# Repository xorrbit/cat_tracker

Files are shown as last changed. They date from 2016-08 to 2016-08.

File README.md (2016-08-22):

# Cat Tracker

This Ardunio project reads location data from a GPS module and writes waypoints to a GPX file on a MicroSD card.

# A Bit More Technical info

This parses NMEA messages sent over a serial channel at 9600 bps. I've configured the NEO-7M to send out updates in low power mode at a rate of 1 Hz. It looks for GPRMC messages to get the lat/lon and date/time, and GPGSA messages to get the PDOP (position degree of precision) / HDOP (horizontal degree of precision) / VDOP (vertical degree of precision).

Once it has this info it creates a new file on the SD card, with the filename based on the date/time as DDHHMMSS.GPX, and starts writing GPX trkpt elements.

It was initially developed for the MSP430 microcontroller but the limited SRAM caused me to port it over to Arduino.

# Development
Since my GPS module/antenna (a uBlox NEO-7M) gets horrible reception indoors, I had to do most of my development and testing outside, so I set up a workstation on my balcony.



This was prototype #2 - switched to an Ardweeny on a breadboard instead of using a full Arduino.


This was prototype #3 - 3xAAA batteries for power, the Ardweeny and MicroSD card adapter (all soldered up), and the GPS module.


Prototype #3 but all taped up in a compact-ish package. SNES cart for scale. Weighs in at 85g or so, with 35g of that being the batteries.




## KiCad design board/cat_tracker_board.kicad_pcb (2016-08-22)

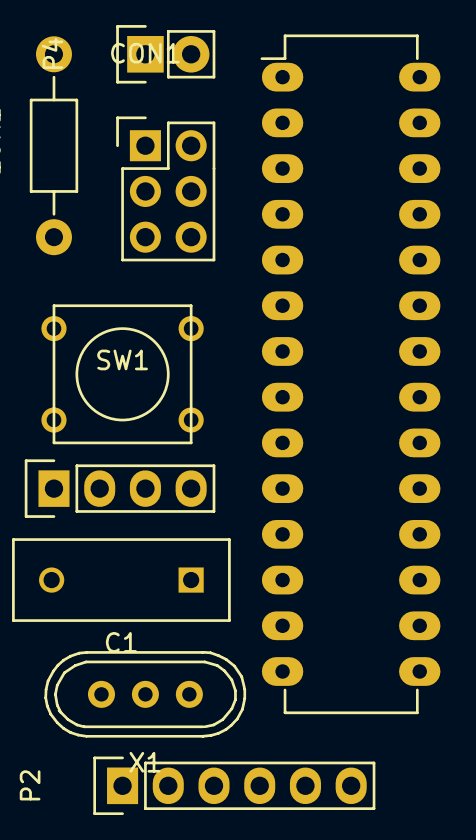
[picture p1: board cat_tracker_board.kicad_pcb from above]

Board: 2 copper layers, 9 parts (0 on the bottom side), 10 nets, no tracks yet.

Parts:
10K1: R; Resistor_Horizontal_RM10mm
C1: 0.1u; C_Disc_D12_P7.75
CON1: AVR-ISP-6; Pin_Header_Straight_2x03
IC1: ATMEGA328-P; DIP-28_W7.62mm_LongPads
P1: GPS_NMEA; Pin_Header_Straight_1x04
P2: MicroSD Card Adapter; Pin_Header_Straight_1x06
P4: BATTERY; Pin_Header_Straight_1x02
SW1: RESET; SW_PUSH_SMALL
X1: 16Mhz XTAL; Crystal_HC49-U_Vertical_3Pin

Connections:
+BATT: 10K1.1, C1.1, CON1.2, IC1.7, IC1.20, IC1.21, P1.1, P2.5, P4.1
GND: C1.2, CON1.6, IC1.8, IC1.22, P1.4, P2.6, P4.2, SW1.2, X1.3
unnamed: 10K1.2, CON1.5, IC1.1, SW1.1
unnamed: CON1.1, IC1.18, P2.4
unnamed: CON1.3, CON1.4, IC1.19, P2.2
unnamed: IC1.9, X1.2
unnamed: IC1.10, X1.1
unnamed: IC1.15, P1.2
unnamed: IC1.16, P2.1
unnamed: IC1.17, P2.3

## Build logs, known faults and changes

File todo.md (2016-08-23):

# To Do
* Get atmega running at lower frequency to save power. Currently it runs at 16 MHz, and a quick test changing the clock prescaler shows it doesn't work properly at 1 MHz, this may be because either the SoftSerial library or the SD card library depends on the 16 MHz clock for some dumb reason.

* Use some low power modes on the atmega. Can turn off the ADC, whatever timers aren't being used, etc. Also can sleep the CPU in between GPS updates, and have it wake up when there is UART activity from the GPS.

* Possibly only turn on the GPS module intermittently. Once every minute or 30 seconds would save a lot of power. It only takes 3 seconds to get a fix upon "hot" power up, which is if all the old satellites it had when powered down are still in view.

* Add a lipo low-voltage cutoff circuit to the schematic, such that you can hook a 1S lipo up to it and run it until it's "dead" (use 80% of the charge) without ruining the lipo. Here is an example, using a S-8261 battery protection IC: https://github.com/rororor/li_prot-02

* Change the footprints to all SMD stuff and make the battery connector footprint a JST plug suitable for a 1S lipo.

* Add open source hardware logo to pcb.

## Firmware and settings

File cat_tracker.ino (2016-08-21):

// xorrbit/cat_tracker

// on prototype
// new gps wiring is
// yellow = gnd
// white = tx
// red = rx (unused)
// black = vcc (lol)

// GPS TX connects to SoftSerial RX (D9, PB9, atmega328 pin 15)
// SoftSerial TX should be set to an unused pin
#define SOFTSERIAL_RX 9
#define SOFTSERIAL_TX 8

// * SD card attached to SPI bus as follows:
// ** CS   - D10 (PB2, atmega328 pin 16)
// ** MOSI - D11 (PB3, atmega328 pin 17)
// ** MISO - D12 (PB4, atmega328 pin 18)
// ** CLK  - D13 (PB5, atmega328 pin 19)
#define SD_CHIP_SELECT 10

#include <SPI.h>
#include <SD.h>
#include <SoftwareSerial.h>
#include <stdlib.h>

#define MAX_NMEA 128
#define MAX_DATETIME 23
#define MAX_FILENAME 11

bool STILL_STARTING = true;
char nmea[MAX_NMEA+1];
double lat = 0.0;
double lon = 0.0;
char datetime[MAX_DATETIME+1];
int i;
unsigned char checksum;
char str[MAX_DATETIME];
File dataFile;
bool sd_working = false;
char filename[MAX_FILENAME+1]; // 08202327.GPX aka MMDDHHMMSS.GPX
double hdop = 99.9;
double pdop = 99.9;
double vdop = 99.9;

SoftwareSerial mySerial(SOFTSERIAL_RX, SOFTSERIAL_TX); // RX, TX

#define logPrint(__blah__) Serial.print(__blah__); if (sd_working) dataFile.print(__blah__)
#define logPrintln(__blah__) Serial.println(__blah__); if (sd_working) dataFile.println(__blah__)

void setup()
{
  Serial.begin(9600);
  while (!Serial)
  {
    ; // wait for serial port to connect. Needed for native USB port only
  }

  // see if the card is present and can be initialized:
  if (!SD.begin(SD_CHIP_SELECT)) {
    Serial.println("Card failed, or not present, only logging to serial port!");
  }

  // we wait for the first good GPS message to get the date and time for this header.
  // we also use this for the log file name

  mySerial.begin(9600);
}

void loop()
{
  if (mySerial.available())
  {
    nmea[0] = mySerial.read();
    
    // if we hit a $, read until a newline
    if (nmea[0] == '$')
    {
      i = 1;
      do
      {
        while (mySerial.available() < 1); // wait for next char
        nmea[i] = mySerial.read();
      } while (nmea[i++] != '\n' && (i < MAX_NMEA));
      
      nmea[--i] = '\0';

      // nmea now contains the message (or the most we could grab of it)
      checkNMEA(nmea);
    }
  }
}

void checkNMEA(char *nmea)
{
  if (nmea[1] == 'G' &&
      nmea[2] == 'P' &&
      nmea[3] == 'R' &&
      nmea[4] == 'M' &&
      nmea[5] == 'C')
  {
    // double check our checksum
    if (calcChecksum(nmea) == (unsigned char) strtoul(&nmea[i-3], 0, 16))
    {
      // this parses out data if we have a fix
      if (parseGPRMC(nmea, &lat, &lon, datetime))
      {
        logGPS(&lat, &lon, datetime, &pdop, &hdop, &vdop); 
      }
    }
  }
  else if (nmea[1] == 'G' &&
           nmea[2] == 'P' &&
           nmea[3] == 'G' &&
           nmea[4] == 'S' &&
           nmea[5] == 'A')
  {
    // double check checksum
    if (calcChecksum(nmea) == (unsigned char) strtoul(&nmea[i-3], 0, 16))
    {
      // parse out pdop, hdop, and vdop
      parseGPGSA(nmea, &pdop, &hdop, &vdop);
    }
  }
}

void logGPS(double *lat, double *lon, char *datetime, double *pdop, double *hdop, double *vdop)
{
  // if our degree of precision is redic high just skip logging
  if (*pdop > 10.0)
    return;

  if (STILL_STARTING)
  {
    // this fixes a weird bug
    // if we don't read sd_working at least once here, the datetime doesn't get output the first time
    if (sd_working) delay(1);
    // DDHHMMSS.GPX aka
    // 2016-08-20T23:27:14.00Z -> 20232714.gpx
    filename[0] = datetime[8];
    filename[1] = datetime[9];
    filename[2] = datetime[11];
    filename[3] = datetime[12];
    filename[4] = datetime[14];
    filename[5] = datetime[15];
    filename[6] = datetime[17];
    filename[7] = datetime[18];
    filename[8] = '.';
    filename[9] = 'G';
    filename[10] = 'P';
    filename[11] = 'X';
    filename[12] = '\0';
    
    dataFile = SD.open(filename, FILE_WRITE);
    if (dataFile)
    {
      sd_working = true;
    }

    logPrintln("<?xml version=\"1.0\" encoding=\"UTF-8\" standalone=\"no\" ?>");
    logPrintln("<gpx creator=\"cat_tracker by xorrbit\">");
    logPrint("<metadata><link href=\"https://github.com/xorrbit/cat_tracker\"><text>xorrbit/cat_tracker on GitHub</text></link><time>");
    logPrint(datetime);
    logPrintln("</time></metadata>");
    logPrintln("<trk><trkseg>");
        
    STILL_STARTING = false;
  }
  else
  {
    // overwrite the footer :)
    if (sd_working)
    {
      dataFile.seek(dataFile.position() - 23);
    }
  }
  
  logPrint("<trkpt lat=\"");
  dtostrf(*lat, 4, 6, str);
  logPrint(str);
  logPrint("\" lon=\"");
  dtostrf(*lon, 4, 6, str);
  logPrint(str);
  logPrint("\"><time>");
  logPrint(datetime);
  logPrint("</time><pdop>");
  dtostrf(*pdop, 4, 2, str);
  logPrint(str);
  logPrint("</pdop><hdop>");
  dtostrf(*hdop, 4, 2, str);
  logPrint(str);
  logPrint("</hdop><vdop>");
  dtostrf(*vdop, 4, 2, str);
  logPrint(str);
  logPrintln("</vdop></trkpt>");
  
  logPrintln("</trkseg></trk></gpx>");

  if (sd_working)
  {
    dataFile.flush();
  }
}

// parse out PDOP (position dilution of precision), HDOP (horizontal dilution of precision), and VDOP (vertical dilution of precision)
void parseGPGSA(char *nmea, double *pdop, double *hdop, double *vdop)
{
  int i = 0;
  int j = 0;
  char dop[10];
  
  // $GPGSA,A,3,,,,,,16,18,,22,24,,,3.6,2.1,2.2*3C
  for (j = 0; j < 15; j++)
  {
    while(nmea[i++] != ','); // skip first 15 fields
  }

  j = 0;
  while(nmea[i] != ',' && nmea[i] != '*')
  {
    dop[j++] = nmea[i++];
  }
  dop[j] == '\0';

  *pdop = strtod(dop, 0);

  i++;
  j = 0;
  while(nmea[i] != ',' && nmea[i] != '*')
  {
    dop[j++] = nmea[i++];
  }
  dop[j] == '\0';

  *hdop = strtod(dop, 0); 

  i++;
  j = 0;
  while(nmea[i] != ',' && nmea[i] != '*')
  {
    dop[j++] = nmea[i++];
  }
  dop[j] == '\0';

  *vdop = strtod(dop, 0);
}

bool parseGPRMC(char *nmea, double *lat, double *lon, char *datetime)
{
  int i = 0;
  int j = 0;
  int latstart = 0;
  char coords[20];
  
  // $GPRMC,time,active,latitude,N/S,longitude,W/E,speed,angle,date,mag,checksum
  while (nmea[i++] != ','); // skip $GPRMC,
  // parse out time
  datetime[10] = 'T';
  datetime[11] = nmea[i++];
  datetime[12] = nmea[i++];
  datetime[13] = ':';
  datetime[14] = nmea[i++];
  datetime[15] = nmea[i++];
  datetime[16] = ':';
  datetime[17] = nmea[i++];
  datetime[18] = nmea[i++];
  datetime[19] = nmea[i++]; // .
  datetime[20] = nmea[i++];
  datetime[21] = nmea[i++];
  datetime[22] = 'Z';
  datetime[23] = '\0';
  i++; // ,
  // if we don't have a fix, return false
  if (nmea[i] != 'A')
  {
    return false;
  }
  while (nmea[i++] != ',');
  // lat  
  coords[j++] = nmea[i++];
  coords[j++] = nmea[i++];
  coords[j] = '\0';

  *lat = strtod(coords, 0);
  j = 0;
  while (nmea[i] != ',')
    coords[j++] = nmea[i++];
  coords[j] = '\0';
  *lat += strtod(coords, 0) / 60.0;
  i++; // ,
  if (nmea[i++] == 'S') // N or S
    *lat = -*lat;
  i++; // ,

  // lon
  j = 0;  
  coords[j++] = nmea[i++];
  coords[j++] = nmea[i++];
  coords[j++] = nmea[i++];
  coords[j] = '\0';

  *lon = strtod(coords, 0);
  j = 0;
  while (nmea[i] != ',')
    coords[j++] = nmea[i++];
  coords[j] = '\0';
  *lon += strtod(coords, 0) / 60.0;
  i++; // ,
  if (nmea[i++] == 'W') // W or E
    *lon = -(*lon);

  i++; // ,
  while (nmea[i++] != ','); // skip speed,
  while (nmea[i++] != ','); // skip angle,

  // parse out date
  datetime[7] = '-';
  datetime[8] = nmea[i++];
  datetime[9] = nmea[i++];
  datetime[4] = '-';
  datetime[5] = nmea[i++];
  datetime[6] = nmea[i++];
  datetime[0] = '2';
  datetime[1] = '0';
  datetime[2] = nmea[i++];
  datetime[3] = nmea[i++];
  
  return true;
}

// it ends with *XX, a checksum
// The checksum field consists of a '*' and two hex digits representing a
// 8 bit exclusive OR of all characters between, but not including,
// the '$' and '*'.
unsigned char calcChecksum(char *nmea)
{
  int i = 1;
  unsigned char sum = 0;
  
  sum = nmea[i++];
  while (nmea[i] != '*')
    sum = sum ^ nmea[i++];
    
  return sum;
}

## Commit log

2016-08-20 Added NMEA message checksum checking and GPRMC valid fix checking.
    [cat_tracker.ino]
2016-08-21 Added KiCad project files.
    [cat_tracker_board.kicad_pcb, cat_tracker_board.sch]
2016-08-21 Added atmega pins and gps pinout, fixed weird bug with Ardweeny.
    [cat_tracker.ino]
2016-08-21 Added a bit of power saving stuff.
2016-08-22 Revert "Added a bit of power saving stuff."
    This reverts commit d84dd544aa0162d0f8ebcea1a0d198b9f4bdbec6.
    [cat_tracker.ino]
2016-08-22 Reworked schematic with xtal.
    [cat_tracker_board.kicad_pcb, cat_tracker_board.sch]
2016-08-22 First pass at a through-hole board layout.
    [cat_tracker_board.kicad_pcb, cat_tracker_board.sch]
